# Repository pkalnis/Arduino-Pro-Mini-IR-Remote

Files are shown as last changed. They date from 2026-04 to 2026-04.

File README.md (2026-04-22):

# LG Smart TV IR Remote — Arduino Pro Mini 3V3
## by Panos Kalnis

A minimal, battery-powered IR remote for LG Smart TVs. Sends NEC-protocol commands for **Power**, **HDMI-1**, **HDMI-2**, and **HDMI-3** input switching.

## Hardware

| Component | Specification |
|---|---|
| MCU | Arduino Pro Mini 3V3 (ATmega328P, 8 MHz) |
| IR LED | 940 nm, driven via 2N2222 NPN transistor |
| Base resistor | 1 kOhm (D3 to 2N2222 base) |
| Emitter resistor | 50 Ohm (2N2222 emitter to GND) |
| Buttons | 4x momentary push buttons (active LOW, internal pull-ups) |
| Power | 3.7 V Li-ion cell connected directly to VCC (regulator bypassed) |

## Wiring

| Pin | Connection |
|---|---|
| VCC | 3.7 V Li-ion (+) (regulator bypassed) |
| GND | 3.7 V Li-ion (-) |
| D3 | 1 kOhm to 2N2222 base (transistor drives IR LED) |
| D4 | Power button to GND |
| D5 | HDMI-1 button to GND |
| D6 | HDMI-2 button to GND |
| D7 | HDMI-3 button to GND |

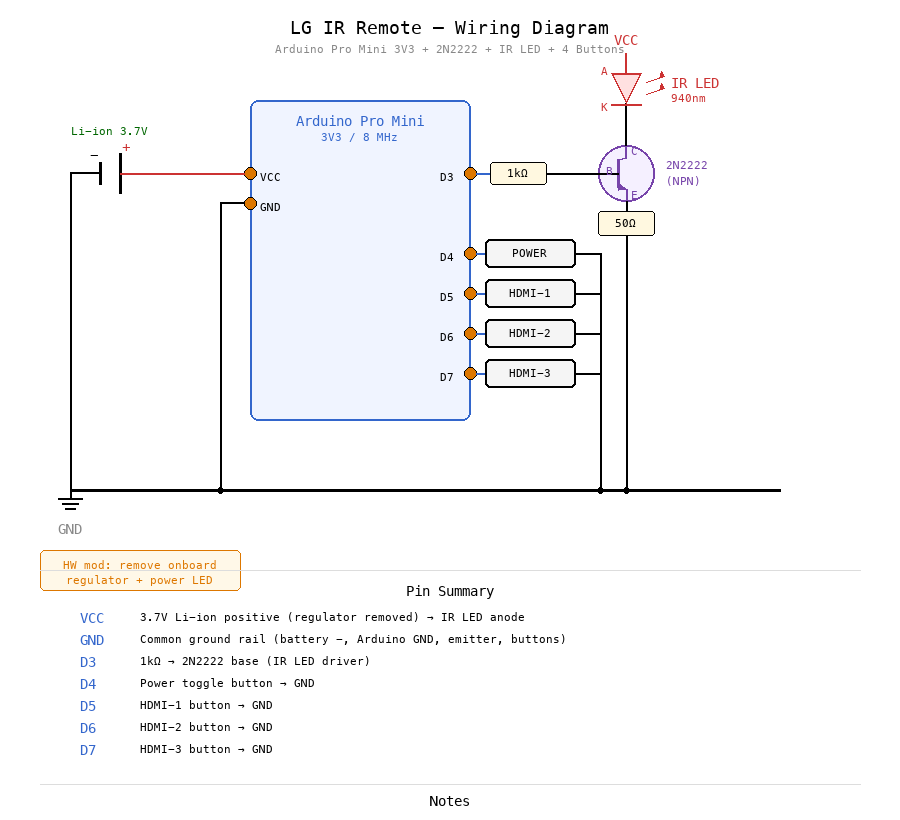
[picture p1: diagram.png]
Wiring Diagram


<details>
<summary>Text diagram</summary>

```
Arduino Pro Mini 3V3

  3.7V Li-ion (+) ──> VCC  (regulator removed)
  3.7V Li-ion (-) ──> GND

  D3 ── 1kΩ ── 2N2222 base
               collector ── IR LED cathode ── (anode to VCC)
               emitter ── 50Ω ── GND

  D4 ──┤ POWER  ├── GND
  D5 ──┤ HDMI-1 ├── GND
  D6 ──┤ HDMI-2 ├── GND
  D7 ──┤ HDMI-3 ├── GND
```

</details>

## IR Protocol

- **Protocol:** NEC, 32-bit, 38 kHz carrier
- **Device address:** `0x04` (inverted: `0xFB`)
- **Frame format:** `(addr)(~addr)(cmd)(~cmd)`

| Button | Command |
|---|---|
| Power | `0x08` |
| HDMI-1 | `0xCE` |
| HDMI-2 | `0xCC` |
| HDMI-3 | `0xE9` |

## Power Saving

- `SLEEP_MODE_PWR_DOWN` between button presses
- Wake via pin-change interrupt (PCINT2) on D4-D7
- ADC, SPI, and TWI peripherals disabled
- BOD disabled during sleep
- Digital input buffers disabled on unused analog pins
- Onboard voltage regulator and power LED removed (hardware mod)

## Dependencies

- [IRremote](https://github.com/Arduino-IRremote/Arduino-IRremote) library

Install via the Arduino IDE Library Manager or `arduino-cli lib install "IRremote"`.

## Building

1. Open `lg_ir_remote/lg_ir_remote.ino` in the Arduino IDE
2. Select **Board:** Arduino Pro or Pro Mini
3. Select **Processor:** ATmega328P (3.3V, 8 MHz)
4. Compile and upload via an FTDI adapter

## 3D-Printed Enclosure

STL files for a two-part enclosure are included in the [`enclosure/`](enclosure/) folder:

| File | Description |
|---|---|
| [`Enclosure Arduino pro mini - Bottom.stl`](enclosure/Enclosure%20Arduino%20pro%20mini%20-%20Bottom.stl) | Bottom housing — holds the Pro Mini, 2N2222, resistors, IR LED, and Li-ion cell |
| [`Enclosure Arduino pro mini - Lid.stl`](enclosure/Enclosure%20Arduino%20pro%20mini%20-%20Lid.stl) | Top lid with openings for the 4 push buttons and the IR LED |

Print both parts in PLA or PETG. Supports are generally not required.

## License

MIT

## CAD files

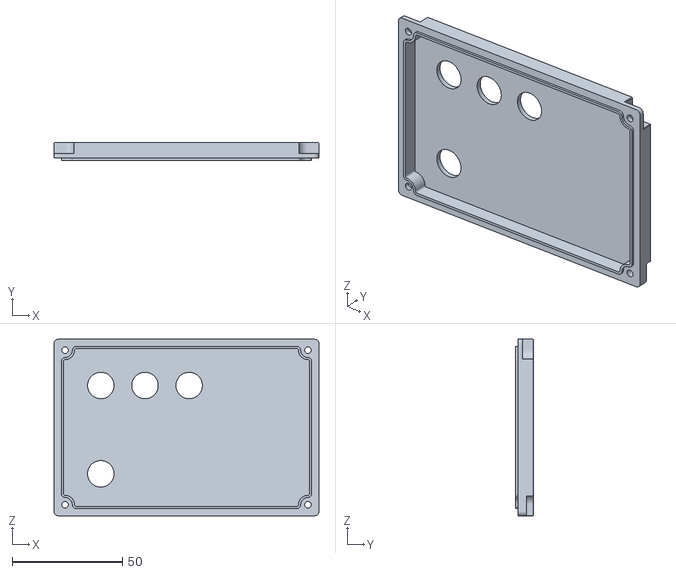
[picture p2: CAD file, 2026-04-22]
enclosure/Enclosure Arduino pro mini - Lid.stl
120.0 x 8.00 x 80.0

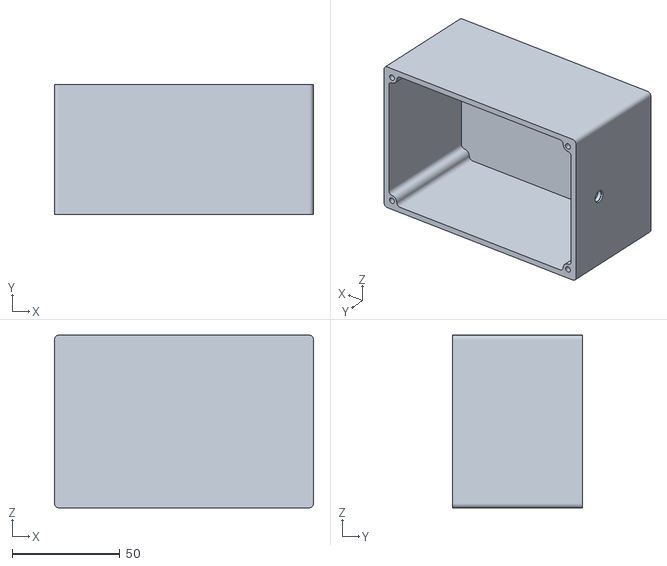
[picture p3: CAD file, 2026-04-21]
enclosure/Enclosure Arduino pro mini - Bottom.stl
120.0 x 60.0 x 80.0

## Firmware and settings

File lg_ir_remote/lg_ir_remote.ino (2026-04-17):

/*
 * LG Smart TV IR Remote — Arduino Pro-Mini 3V3
 * =============================================
 *
 * Board:    Arduino Pro Mini 3V3 (ATmega328P, 8 MHz)
 * Library:  IRremote (https://github.com/Arduino-IRremote/Arduino-IRremote)
 *
 * Wiring summary:
 *   D3 -> 1 kOhm -> 2N2222 base
 *   2N2222 collector -> IR LED cathode
 *   IR LED anode -> VCC (3.7 V Li-ion)
 *   2N2222 emitter -> 50 Ohm resistor -> GND
 *
 *   Power button  -> Pin D4 -> GND  (internal pull-up, active LOW)
 *   HDMI-1 button -> Pin D5 -> GND  (internal pull-up, active LOW)
 *   HDMI-2 button -> Pin D6 -> GND  (internal pull-up, active LOW)
 *   HDMI-3 button -> Pin D7 -> GND  (internal pull-up, active LOW)
 *
 *   Power supply: 3.7 V Li-ion cell -> VCC pin (regulator bypassed)
 *
 * Hardware mod (required):
 *   - Remove onboard voltage regulator (or desolder)
 *   - Remove onboard power LED (or desolder)
 *   This eliminates ~5-10 mA quiescent draw and allows true uA-level sleep.
 *
 * Power saving:
 *   - SLEEP_MODE_PWR_DOWN between presses
 *   - Wake on pin-change interrupt (PCINT2 / PORTD)
 *   - ADC, BOD, and unused peripherals disabled
 */

#include <IRremote.hpp>
#include <avr/sleep.h>
#include <avr/power.h>

/* ── Pin assignments ─────────────────────────────────────────────── */
static const uint8_t PIN_IR_LED     = 3;   // Timer2 OC2B output

static const uint8_t PIN_BTN_POWER  = 4;
static const uint8_t PIN_BTN_HDMI1  = 5;
static const uint8_t PIN_BTN_HDMI2  = 6;
static const uint8_t PIN_BTN_HDMI3  = 7;

static const uint8_t BUTTON_PINS[]  = {
  PIN_BTN_POWER, PIN_BTN_HDMI1, PIN_BTN_HDMI2, PIN_BTN_HDMI3
};
static const uint8_t BUTTON_COUNT   = sizeof(BUTTON_PINS) / sizeof(BUTTON_PINS[0]);

/* ── LG NEC protocol constants ───────────────────────────────────── */
static const uint16_t LG_ADDRESS    = 0x04;  // device address (inverted byte handled by lib)
static const uint8_t  CMD_POWER     = 0x08;
static const uint8_t  CMD_HDMI1     = 0xCE;
static const uint8_t  CMD_HDMI2     = 0xCC;
static const uint8_t  CMD_HDMI3     = 0xE9;

/* Command lookup — index matches BUTTON_PINS order */
static const uint8_t COMMANDS[]     = {
  CMD_POWER, CMD_HDMI1, CMD_HDMI2, CMD_HDMI3
};

/* ── Timing constants ────────────────────────────────────────────── */
static const uint8_t  DEBOUNCE_MS   = 50;
static const uint8_t  NEC_REPEATS   = 2;    // total transmissions per press

/* ── Forward declarations ────────────────────────────────────────── */
static void enterSleep();
static void disableUnusedPeripherals();

/* ── Pin-change ISR (empty — only purpose is to wake the MCU) ──── */
ISR(PCINT2_vect) {
  /* intentionally empty */
}

/* ================================================================ */
void setup() {
  /* Configure button pins with internal pull-ups */
  for (uint8_t i = 0; i < BUTTON_COUNT; i++) {
    pinMode(BUTTON_PINS[i], INPUT_PULLUP);
  }

  /* Initialise IR sender on pin 3 */
  IrSender.begin(PIN_IR_LED);

  /* Disable peripherals we don't need */
  disableUnusedPeripherals();

  /* Enable pin-change interrupts on PORTD (PCINT20..23 = D4..D7) */
  PCICR  |= (1 << PCIE2);
  PCMSK2 |= (1 << PCINT20) | (1 << PCINT21) | (1 << PCINT22) | (1 << PCINT23);
}

/* ================================================================ */
void loop() {
  /* Scan buttons (active LOW) */
  for (uint8_t i = 0; i < BUTTON_COUNT; i++) {
    if (digitalRead(BUTTON_PINS[i]) == LOW) {
      delay(DEBOUNCE_MS);

      /* Confirm the press is still held after debounce */
      if (digitalRead(BUTTON_PINS[i]) == LOW) {
        IrSender.sendNEC(LG_ADDRESS, COMMANDS[i], NEC_REPEATS);

        /* Wait for button release before sleeping */
        while (digitalRead(BUTTON_PINS[i]) == LOW) {
          /* spin until released */
        }
        delay(DEBOUNCE_MS);  // debounce release
      }
    }
  }

  enterSleep();
}

/* ── Power-management helpers ────────────────────────────────────── */

static void disableUnusedPeripherals() {
  /* Disable ADC */
  ADCSRA &= ~(1 << ADEN);
  power_adc_disable();

  /* Disable peripherals not needed */
  power_spi_disable();
  power_twi_disable();

  /* Disable digital input buffers on analog pins (saves ~1 uA each) */
  DIDR0 = 0x3F;  // ADC0..ADC5
  DIDR1 = 0x03;  // AIN0, AIN1
}

static void enterSleep() {
  set_sleep_mode(SLEEP_MODE_PWR_DOWN);
  cli();
  sleep_enable();

  /* Disable BOD during sleep (ATmega328P fuse-controlled, software assist) */
  sleep_bod_disable();

  sei();
  sleep_cpu();

  /* ── Execution resumes here after wake-up ── */
  sleep_disable();
}

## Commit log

2026-04-17 Initial commit: LG IR remote for Arduino Pro Mini 3V3
    NEC-protocol IR remote with Power, HDMI-1/2/3 buttons.
    Includes PWR_DOWN sleep, pin-change wake, and wiring diagrams.
2026-04-17 Use VCC instead of RAW, add regulator/LED removal mod
    Li-ion connects directly to VCC for true uA-level sleep current.
    Added pin assignments and collaboration notes to CLAUDE.md.
    Fixed IR LED GND visibility in PNG diagram.
    [lg_ir_remote.ino]
2026-04-17 Add 2N2222 NPN transistor driver for IR LED
    GPIO at 3.3V delivers insufficient current to drive the IR LED.
    2N2222 switches the full battery voltage (~4.2V) through the LED,
    giving ~28 mA vs the ~10-15 mA from the GPIO pin directly.
2026-04-17 Fix IR LED polarity in diagram, reduce emitter resistor to 50Ω
    LED symbol was drawn with reversed polarity; now correctly shows
    anode to VCC and cathode to 2N2222 collector. Emitter resistor
    changed from 100Ω to 50Ω for ~55 mA peak LED current.
    [lg_ir_remote.ino]
2026-04-20 Rework diagrams: NPN symbol, battery symbol, common GND rail
    PNG: replace transistor rectangle with NPN schematic symbol;
    replace battery rectangle with standard battery symbol; route
    VCC as a horizontal bus; tie battery (-), Arduino GND, 2N2222
    emitter, and all 4 button returns to a single common ground rail.
    TXT: fix button ground side (pin signal trace was incorrectly
    labeled GND); restructure as Power rail + IR driver + Buttons
    sections for clarity.
2026-04-21 Add 3D-printed enclosure STL files
    Two-part enclosure: bottom housing for electronics and Li-ion cell,
    lid with button and IR LED openings. README updated with a section
    linking to both STLs.
    [Enclosure Arduino pro mini - Bottom.stl, Enclosure Arduino pro mini - Lid.stl]
2026-04-22 Add author credit; update lid STL
    [Enclosure Arduino pro mini - Lid.stl]
